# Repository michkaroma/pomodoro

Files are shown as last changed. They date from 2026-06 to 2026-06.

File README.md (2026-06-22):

# 🍅 Arduino Pomodoro Timer

A physical Pomodoro timer built around an Arduino Nano, a 32×8 LED matrix, an OLED display, a rotary encoder, and a buzzer. Designed as a dedicated, distraction-free productivity device — no phone, no computer, just focused work.

The full Pomodoro cycle (work → short break → work → long break) runs automatically, all durations are adjustable on the device itself, and the remaining time is displayed in large hand-drawn digits on the LED matrix. The electronics are housed in a custom 3D-printed enclosure.

> Prototyped and simulated with [Wokwi](https://wokwi.com) before hardware assembly. Built with [PlatformIO](https://platformio.org).

---

## Demo

| Finished device | Top view | OLED menu |
|:---:|:---:|:---:|
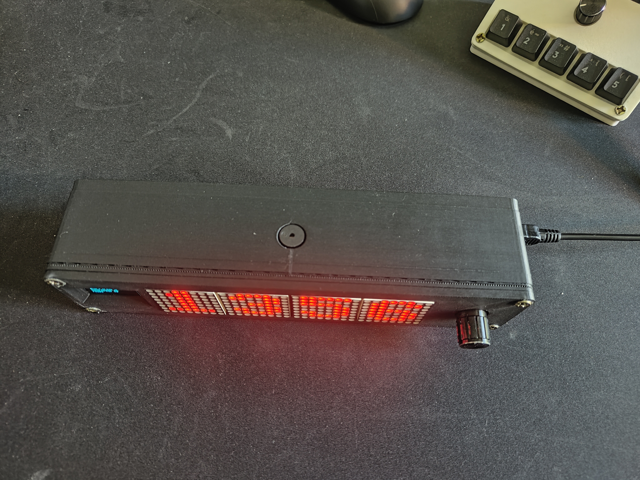
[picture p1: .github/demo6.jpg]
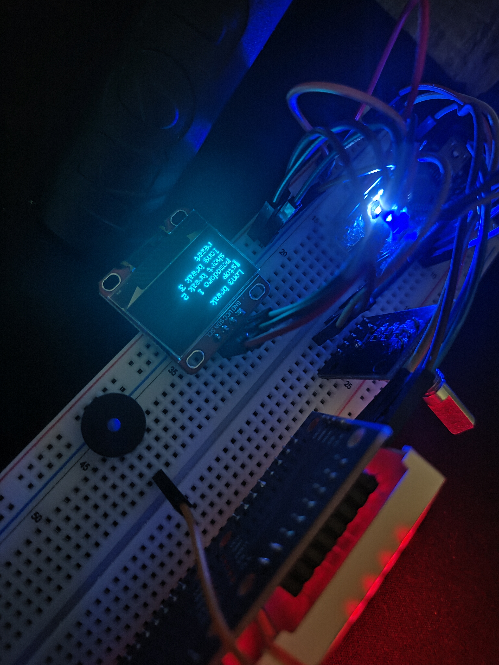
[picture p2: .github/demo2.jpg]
|  |  |  |

| In action (breadboard) | Wokwi simulation |
|:---:|:---:|
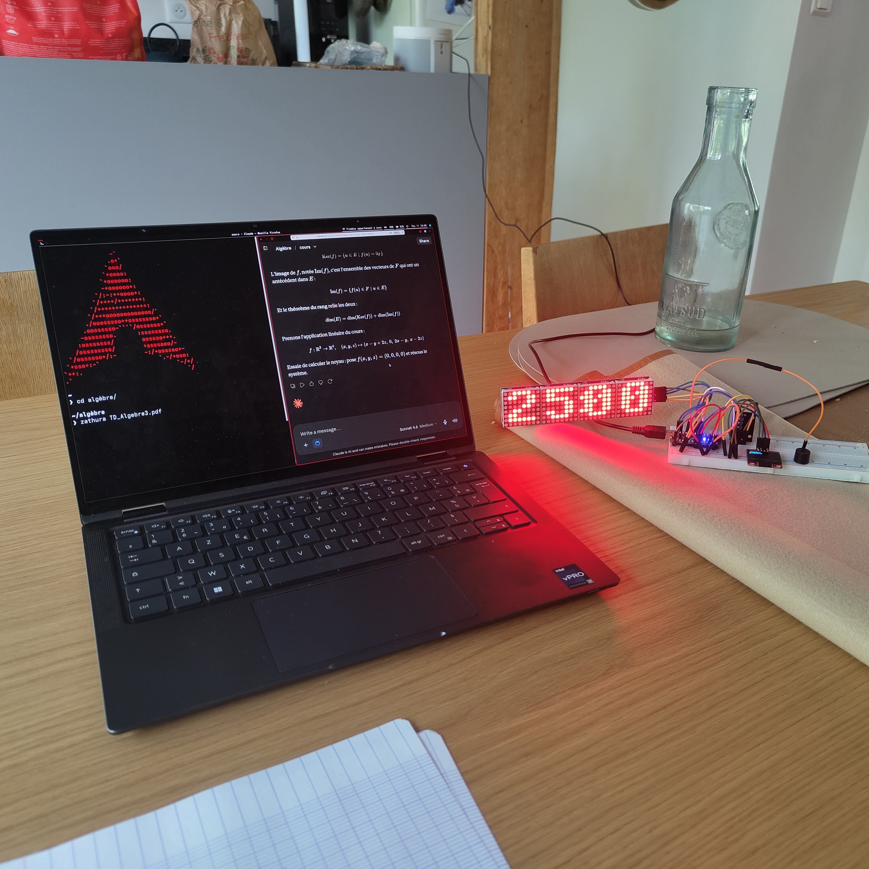
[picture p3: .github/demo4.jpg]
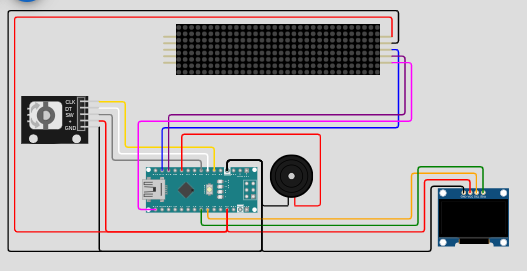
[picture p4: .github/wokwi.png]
|  |  |

---

## Features

- **Full Pomodoro cycle** — automatically chains work sessions and breaks: `Pomodoro → short break → Pomodoro → long break`, then repeats.
- **Adjustable durations** — set the length of each phase (Pomodoro / short break / long break) directly on the device with the rotary encoder.
- **Large countdown display** — minutes and seconds shown across the 32×8 LED matrix using hand-drawn 8×8 digit bitmaps.
- **OLED menu** — navigate options, start/stop the timer, and read the current phase on the 128×64 screen.
- **Adjustable brightness** — cycle through 4 brightness levels for the LED matrix.
- **Buzzer alert** — audio signal at the end of each phase.
- **Reset** — return to the start of a fresh Pomodoro cycle at any time.
- **Custom 3D-printed enclosure** — turns the breadboard prototype into a finished desk device.

---

## Hardware

| Component | Description |
|---|---|
| Arduino Nano | Microcontroller (ATmega328P) |
| LED Matrix 32×8 | 4× MAX7219-driven 8×8 modules, chained |
| OLED Display | 128×64 SSD1306, I²C |
| Rotary Encoder | KY-040 digital encoder with push button |
| Buzzer | Passive buzzer |
| Breadboard + jumper wires | Prototyping setup |
| 3D-printed enclosure | Custom case (see [`3d/`](3d/)) |

---

## Wiring

### LED Matrix — MAX7219 (`LedControl(DIN=11, CLK=13, CS=10, 4 devices)`)
| Arduino Nano | Matrix |
|---|---|
| D11 | DIN |
| D13 | CLK |
| D10 | CS |
| 5V | V+ |
| GND | GND |

### OLED Display — SSD1306 (I²C, address `0x3C`)
| Arduino Nano | OLED |
|---|---|
| A4 | SDA |
| A5 | SCL |
| 5V | VCC |
| GND | GND |

### Rotary Encoder — KY-040
| Arduino Nano | Encoder |
|---|---|
| D3 | CLK |
| D4 | DT |
| D5 | SW (push button) |
| 5V | VCC |
| GND | GND |

> `D3` is used as an interrupt pin (`attachInterrupt` on `CHANGE`) for reliable rotation detection.

### Buzzer
| Arduino Nano | Buzzer |
|---|---|
| D8 | + |
| GND | − |

---

## Enclosure

The electronics are housed in a custom enclosure modeled in **Fusion 360** and 3D-printed. The case makes the LED matrix, OLED and rotary encoder accessible on the front face, and routes the power cable cleanly out the side.

Design files are in the [`3d/`](3d/) folder:

| File | Description |
|---|---|
| `pomodoro.f3d` | Editable Fusion 360 source model |
| `pomodoro.3mf` | Print-ready mesh (slice and print directly) |

---

## Software

- **Language:** C++
- **Build system:** [PlatformIO](https://platformio.org)
- **Simulation:** [Wokwi](https://wokwi.com)

### Libraries

| Library | Purpose |
|---|---|
| `LedControl` | MAX7219 LED matrix driver |
| `Adafruit_SSD1306` | OLED display driver |
| `Adafruit_GFX` | Graphics primitives for the OLED |
| `Wire` | I²C communication (built-in) |

Declare them in `platformio.ini` under `lib_deps`.

---

## How It Works

1. On startup the OLED shows the menu: **play/stop**, **pomodoro**, **short break**, **long break**, **reset** (plus a second page for **brightness**).
2. Rotating the encoder moves the cursor through the menu; pressing the button selects an item.
3. Selecting a duration entry (e.g. *pomodoro*) opens a quick editor where you turn the encoder to set the minutes (0–99) and press to confirm.
4. Pressing **play** starts the countdown, rendered on the LED matrix.
5. When a phase reaches `0`, the buzzer sounds and the firmware advances to the next phase in the cycle:

   ```
   Pomodoro ──▶ Short break ──▶ Pomodoro ──▶ Long break ──▶ (repeat)
   ```

6. **Reset** returns to a fresh Pomodoro at any time.

The countdown digits are drawn by writing custom 8×8 bitmaps (defined in the `digits[10][8]` array) to each of the four matrix modules — one module per digit — and the timer counts down on a 1-second interval driven by `millis()`.

---

## Getting Started

### Prerequisites

- [PlatformIO](https://platformio.org) (recommended) or the Arduino IDE
- The libraries listed above

### Build & Upload (PlatformIO)

```bash
git clone https://github.com/michkaroma/pomodoro.git
cd pomodoro
pio run --target upload
```

### Simulate (Wokwi)

The repo includes `diagram.json` and `wokwi.toml`, so the project can be run directly in the [Wokwi VS Code extension](https://docs.wokwi.com/vscode/getting-started).

### Print the enclosure

Slice `3d/pomodoro.3mf` in your slicer of choice and print. Open `3d/pomodoro.f3d` in Fusion 360 if you want to tweak the dimensions.

---

## Project Structure

```
pomodoro/
├── 3d/
│   ├── pomodoro.3mf    # Print-ready mesh
│   └── pomodoro.f3d    # Fusion 360 source model
├── diagram.json        # Wokwi circuit definition
├── wokwi.toml          # Wokwi simulation config
├── platformio.ini      # PlatformIO project config
├── include/
├── lib/
├── src/
│   └── main.cpp        # Main firmware
└── test/
```

---

## Possible Improvements

- Persist custom durations to **EEPROM** so they survive a power cycle (scaffolding is present in the source).
- End-of-phase **melodies** instead of simple beeps (commented-out note tables included).

---

## Context

Personal project built during studies at **ECE Paris** — and put to use revising for end-of-term exams.
Goal: practice embedded C++ programming, I²C/SPI bus management, interrupt-driven inputs, hardware prototyping, and 3D enclosure design.

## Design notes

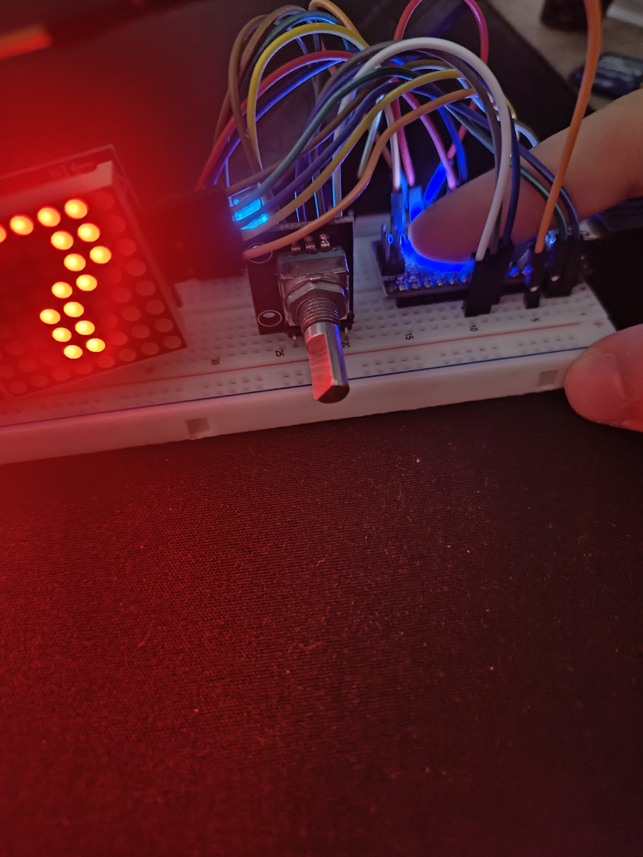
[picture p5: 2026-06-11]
.github/demo3.jpg

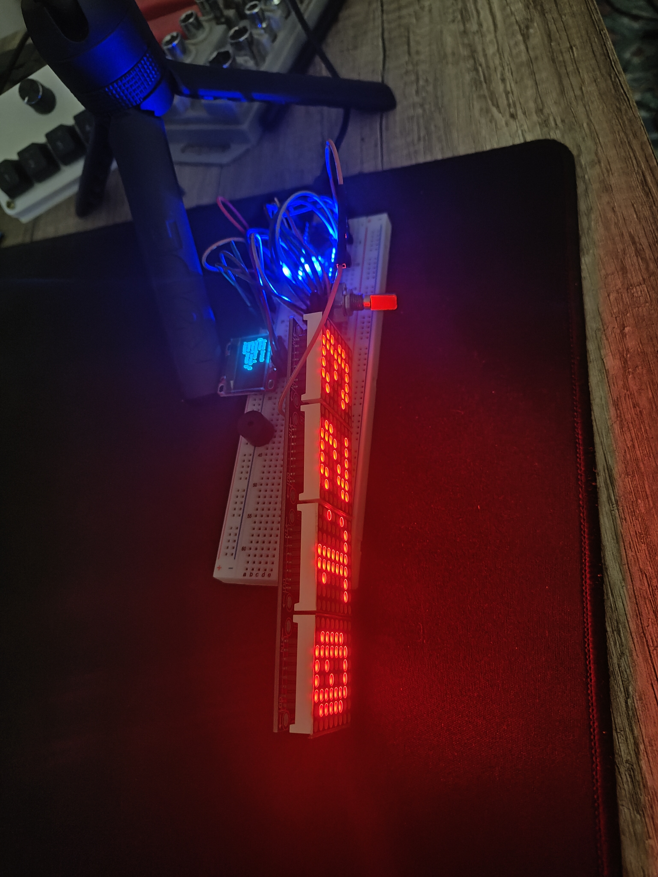
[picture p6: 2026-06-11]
.github/demo1.jpg

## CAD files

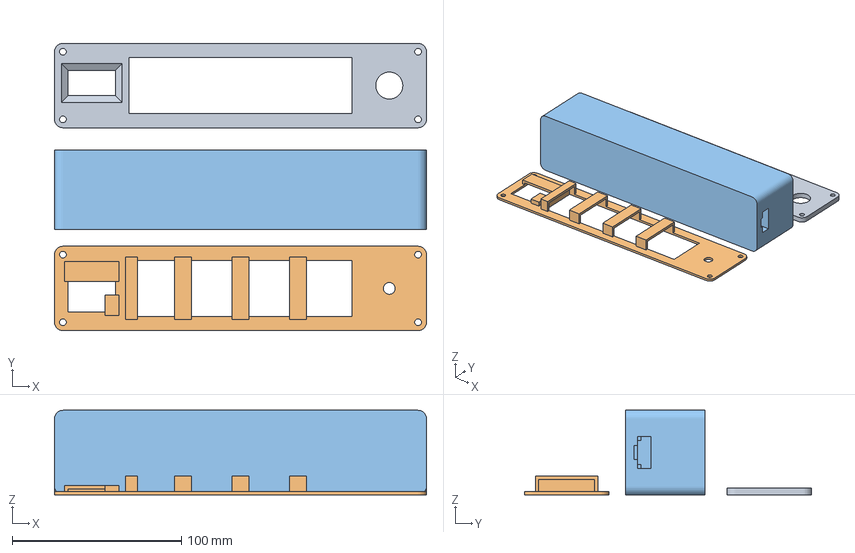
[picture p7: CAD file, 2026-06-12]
3d/pomodoro.3mf
220.0 x 170.0 x 50.0 mm

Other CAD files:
3d/pomodoro.f3d

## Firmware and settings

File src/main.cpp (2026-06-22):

#include <LedControl.h>
#include <Wire.h>
#include <Adafruit_SSD1306.h>
#include <Adafruit_GFX.h>
//#include <EEPROM.h>

//note utilisé par le buzzer
/*#define NOTE_B3  247
#define NOTE_C4  262
#define NOTE_CS4 277
#define NOTE_D4  294
#define NOTE_E4  330
#define NOTE_F4  349
#define NOTE_FS4 370
#define NOTE_G4  392
#define NOTE_B4  494
#define NOTE_C5  523
*/
//PIN
#define buzzer 8
#define pinArduinoRaccordementSignalSW  5
#define pinArduinoRaccordementSignalCLK 3
#define pinArduinoRaccordementSignalDT  4
#define PIN_TRIG 7
#define PIN_ECHO 6

//dimension écran
#define SCREEN_WIDTH 128
#define SCREEN_HEIGHT 64

//constantes
#define nombre_choix_menu 5

//informations EEPROM
////const byte LongueurSon[2] = {32,33};
//const byte AdresseNotes[2] = {0,AdresseNotes[0]+sizeof(int)*LongueurSon[0]+1+sizeof(byte)*LongueurSon[0]+1};
//const byte AdresseTemps[2] = {AdresseNotes[0]+sizeof(int)*LongueurSon[0]+1,AdresseNotes[1]+sizeof(int)*LongueurSon[0]+1};

//initialisation de différent truc
LedControl matriceled = LedControl(11, 13, 10, 4);
Adafruit_SSD1306 display(SCREEN_WIDTH, SCREEN_HEIGHT, &Wire, -1);

//variables
byte menu=0;
int etatPrecedentLigneCLK = digitalRead(pinArduinoRaccordementSignalCLK);
int etatPrecedentLigneDT  = digitalRead(pinArduinoRaccordementSignalDT);
int compteur = nombre_choix_menu;
byte intensite=0;
int secondeMinuteur=0;
byte minuteurActiv=0;
int stageTime[3]={25,5,15};
int time=stageTime[0]*60;
String stageName[3]={"Pomodoro","Short break","Long break"};
byte activite=0;
boolean pause=true;
byte stage=0;
unsigned long lastSecond= millis();
boolean longBreak=false;

//dessin des chiffres dans la matrices led
byte digits[10][8] = {
  {0b00111100, 0b01100110, 0b01101110, 0b01110110, 0b01100110, 0b01100110, 0b00111100, 0b00000000},
  {0b00011000, 0b00111000, 0b00011000, 0b00011000, 0b00011000, 0b00011000, 0b01111110, 0b00000000},
  {0b00111100, 0b01100110, 0b00000110, 0b00001100, 0b00110000, 0b01100000, 0b01111110, 0b00000000},
  {0b00111100, 0b01100110, 0b00000110, 0b00011100, 0b00000110, 0b01100110, 0b00111100, 0b00000000},
  {0b00001100, 0b00011100, 0b00101100, 0b01001100, 0b01111110, 0b00001100, 0b00011110, 0b00000000},
  {0b01111110, 0b01100000, 0b01111100, 0b00000110, 0b00000110, 0b01100110, 0b00111100, 0b00000000},
  {0b00111100, 0b01100110, 0b01100000, 0b01111100, 0b01100110, 0b01100110, 0b00111100, 0b00000000},
  {0b01111110, 0b01100110, 0b00000110, 0b00001100, 0b00011000, 0b00011000, 0b00011000, 0b00000000},
  {0b00111100, 0b01100110, 0b01100110, 0b00111100, 0b01100110, 0b01100110, 0b00111100, 0b00000000},
  {0b00111100, 0b01100110, 0b01100110, 0b00111110, 0b00000110, 0b01100110, 0b00111100, 0b00000000} 
};


void changementSurLigneCLK() {
  int etatActuelDeLaLigneCLK = digitalRead(pinArduinoRaccordementSignalCLK);
  int etatActuelDeLaLigneDT  = digitalRead(pinArduinoRaccordementSignalDT);

  if((etatActuelDeLaLigneCLK == HIGH) && (etatActuelDeLaLigneDT == LOW) && (etatPrecedentLigneCLK == LOW) && (etatPrecedentLigneDT == HIGH)) compteur++;
  if((etatActuelDeLaLigneCLK == HIGH) && (etatActuelDeLaLigneDT == HIGH) && (etatPrecedentLigneCLK == LOW) && (etatPrecedentLigneDT == LOW)) compteur--;

  etatPrecedentLigneCLK = etatActuelDeLaLigneCLK;
  etatPrecedentLigneDT = etatActuelDeLaLigneDT;
}

/*void initialisationDesSonsDansEEPROM() {
  //son 1
  int notes1[LongueurSon[0]] = {
    NOTE_C4, NOTE_E4, NOTE_G4, NOTE_C5,
    NOTE_G4, NOTE_F4, NOTE_E4, NOTE_D4,
    NOTE_E4, NOTE_G4, NOTE_B4, NOTE_C5,
    NOTE_C5, NOTE_B4, NOTE_G4, NOTE_C4,
    NOTE_C4, NOTE_E4, NOTE_G4, NOTE_C5,
    NOTE_G4, NOTE_F4, NOTE_E4, NOTE_D4,
    NOTE_E4, NOTE_G4, NOTE_B4, NOTE_C5,
    NOTE_C5, NOTE_B4, NOTE_G4, NOTE_C4
  };

  byte temps1[LongueurSon[0]] = {
    30, 30, 30, 60,
    30, 30, 30, 60,
    30, 30, 30, 60,
    30, 30, 30, 60,    
    30, 30, 30, 60,
    30, 30, 30, 60,
    30, 30, 30, 60,
    30, 30, 30, 100
  };

  //son 2
  int notes2[LongueurSon[0]] = {
    NOTE_FS4, NOTE_E4, NOTE_D4, NOTE_E4, NOTE_FS4, NOTE_E4, NOTE_D4, NOTE_B3,
    NOTE_D4, NOTE_FS4, NOTE_E4, NOTE_D4, NOTE_CS4, NOTE_B3, NOTE_CS4, NOTE_D4,
    NOTE_B3, NOTE_CS4, NOTE_D4, NOTE_E4, NOTE_FS4, NOTE_E4, NOTE_D4, NOTE_E4,
    NOTE_FS4, NOTE_E4, NOTE_D4, NOTE_B3, NOTE_D4, NOTE_CS4, NOTE_B3, NOTE_CS4, NOTE_D4
  };

  byte temps2[LongueurSon[0]] = {
    20, 20, 20, 20, 20, 20, 20, 40,
    20, 20, 20, 20, 20, 20, 20, 40,
    20, 20, 20, 20, 20, 20, 20, 20,
    20, 20, 20, 40, 20, 20, 20, 20, 60
  };

  //ecriture dans l'EEPROM
  for (int i = 0; i < LongueurSon[0]; i++) {
    EEPROM.put(AdresseNotes[0] + i*sizeof(int), notes1[i]);
    EEPROM.put(AdresseTemps[0] + i*sizeof(byte), temps1[i]);
  }
  for (int i = 0; i < LongueurSon[0]; i++) {
    EEPROM.put(AdresseNotes[1] + i*sizeof(int), notes2[i]);
    EEPROM.put(AdresseTemps[1] + i*sizeof(byte), temps2[i]);
  }
}*/

void setup() {
  Serial.begin(115200);

  //setup matrices led
  for (int i = 0; i < 4; i++) {
    matriceled.shutdown(i, false);
    matriceled.setIntensity(i, intensite);
    matriceled.clearDisplay(i);
  }

  //setup écran Oled
  if(!display.begin(SSD1306_SWITCHCAPVCC, 0x3C)) {
  Serial.println(F("SSD1306 allocation failed"));
  for(;;);
  }
  

  //setup buzzer
  pinMode(buzzer,OUTPUT);

  //setup encodeur numérique
  pinMode(pinArduinoRaccordementSignalSW, INPUT_PULLUP);
  pinMode(pinArduinoRaccordementSignalCLK, INPUT);
  pinMode(pinArduinoRaccordementSignalDT, INPUT);
  etatPrecedentLigneCLK = digitalRead(pinArduinoRaccordementSignalCLK);
  etatPrecedentLigneDT  = digitalRead(pinArduinoRaccordementSignalDT);
  attachInterrupt(digitalPinToInterrupt(pinArduinoRaccordementSignalCLK), changementSurLigneCLK, CHANGE);   // CHANGE => détecte tout changement d'état


  //initialisationDesSonsDansEEPROM();
  
  delay(2000);
}

void affichage_chiffre(byte matrice, byte chiffre) {
  for (byte i = 0; i < 8; i++) {
    matriceled.setRow(matrice, i, digits[chiffre][i]); 
  }
}

void affichageTime(){
  if(millis()-lastSecond>=1000 && !pause){
    time--;
    lastSecond=millis();
  }
  int minutes=(time/60);
  int secondes=(time%60);
  //affichage des minutes
  affichage_chiffre(3, minutes/10);
  affichage_chiffre(2, minutes%10);
  //affichage des secondes
  affichage_chiffre(1,secondes/10);
  affichage_chiffre(0,secondes%10);
}

void timeSettings(byte s){
  int currentTime=stageTime[s];
  

  display.setTextSize(2);
  display.setTextColor(WHITE);

  compteur=stageTime[s];
  delay(200);

  while(digitalRead(pinArduinoRaccordementSignalSW) == HIGH){
    if(compteur<0)compteur=99;
    if(compteur>99)compteur=0;
    stageTime[s]=compteur;
    //initialisation écran
    display.clearDisplay();
    //affichage Titre de section
    display.setTextSize(1);
    display.setCursor(5, 5 );
    display.print(stageName[s]);
    //affichage du nouveau temps
    display.setTextSize(3);
    display.setCursor(40, 30);
    display.print(compteur/10);
    display.print(compteur%10);
    //actualisation écran
    display.display();
  }
  if(pause)time=stageTime[stage]*60;
  compteur=nombre_choix_menu;
}

void fctMenu(){

  //initialisation écran
  display.clearDisplay();
  display.setTextSize(1);
  display.setTextColor(WHITE);
  if(compteur<0)compteur=nombre_choix_menu;
  if(compteur>nombre_choix_menu)compteur=0;
  menu=abs(compteur-nombre_choix_menu);
  
  //affichage indication de réglages
  display.setCursor(5,0);
  display.print(stageName[stage]);

  //affichage menu
  //page 1
  if(menu<5){
    display.setCursor(5, 10);
    if(pause)display.print("play"); else display.print("stop");
    display.setCursor(5, 20);
    display.print("pomodoro ");
    display.print(stageTime[0]);
    display.setCursor(5, 30);
    display.print("short break ");
    display.print(stageTime[1]);
    display.setCursor(5, 40);
    display.print("long break ");
    display.print(stageTime[2]);
    display.setCursor(5, 50);
    display.print("reset");
  }
  //page 2
  else{
    display.setCursor(5, 10);
    display.print("intensite");
  }

  //affichage curseur
  display.fillRect(0,10+((menu%5)*10),3,10,WHITE);
  display.display();

  //interaction menu
  if(digitalRead(pinArduinoRaccordementSignalSW) == LOW){
    switch(menu){
      case 0:
        pause=!pause;
        break;
      case 1:
        timeSettings(0);
        break;
      case 2:
        timeSettings(1);
        break;
      case 3:
        timeSettings(2);
        break;
      case 4:
        longBreak=false;
        stage=0;
        pause=true;
        time=stageTime[0]*60;
        break;
      case 5:
        intensite=(intensite+4)%16;
        for (int i = 0; i < 4; i++) {
          matriceled.setIntensity(i, intensite);
        }
        break ;
    }
    delay(300);
  }
}

void sonnerie(){
  tone(buzzer, 250);
  delay(500);
  noTone(buzzer);
  delay(250);
  tone(buzzer, 300);
  delay(500);
  noTone(buzzer);

  /*if(0){
    for (byte j = 0; j < LongueurSon[0]; j++) {
      int notes;
      byte temps;
      EEPROM.get(AdresseNotes[1] + j*sizeof(int),notes);
      EEPROM.get(AdresseTemps[1] + j*sizeof(byte),temps);
      tone(buzzer, notes);
      delay(temps * 10);
      noTone(buzzer);
      if(digitalRead(pinArduinoRaccordementSignalSW) == LOW) j=LongueurSon[0];
      digitalWrite(PIN_TRIG, HIGH);
      delayMicroseconds(10);
      digitalWrite(PIN_TRIG, LOW);
      int duration = pulseIn(PIN_ECHO, HIGH);
    }
  }*/
}


void loop() {
  affichageTime();
  if(time<=0){
    switch(stage){
      case 0:
        if(longBreak)stage+=2;else stage++;
        longBreak=!longBreak;
        break;
      case 1:
        stage=0;
        break;
      case 2:
        stage=0;
        break;
    }
    time=stageTime[stage]*60;
    sonnerie();
  }
  fctMenu();
}

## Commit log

2026-06-10 long break every 2 cycle + reset bouton
    [main.cpp]
2026-06-12 3d support corrigé
    [pomodoro.3mf, pomodoro.f3d]
2026-06-22 pomo -> short break -> pomo -> long break
    [main.cpp]
